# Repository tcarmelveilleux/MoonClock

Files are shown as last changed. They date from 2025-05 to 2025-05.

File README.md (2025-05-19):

# MoonClock

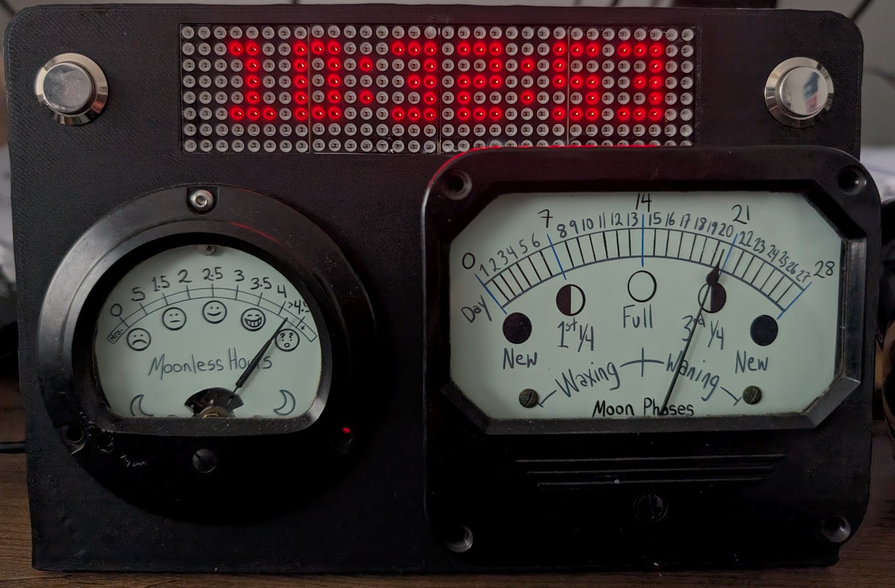
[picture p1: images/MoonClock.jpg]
MoonClock in action


A unique analog and digital clock that displays the current phase of the moon and the number of hours of darkness available for astronomical observation in the evening.

## Features

* **Analog Moon Phase Dial:** Visually represents the current lunar phase using a modified micro-ammeter.
* **Analog Darkness Hours Dial:** Indicates the duration of darkness in the evening after astronomical twilight, crucial for stargazing, using a modified micro-ammeter.
* **Digital Time Display:** A dot matrix display shows the current time.
* **Real-Time Clock (RTC):** Keeps accurate time, even when not powered.
* **3D Printed Frame:** The clock's frame is a single piece designed to be 3D printed.
* **Powered by Raspberry Pi RP2040:** Uses the WaveShare RP2040-Zero module for its easy to use form-factor.
* **CircuitPython Implementation:** The project is coded in CircuitPython, making it accessible and easy to modify.
* **Custom Astronomical Calculations:** Employs the `tcv_astro` module, specifically developed for this project using algorithms from astronomical literature (primarily "Astronomical Algorithms" by Jean Meeus).

## Hardware

* Raspberry Pi RP2040-based module (e.g., Waveshare RP2040-Zero)
* Real-Time Clock (RTC) module based on DS3231 (Rev 1) and MCP7940 (Rev 2)
* Dot matrix display based on MAX7219
* Modified micro-ammeters analog dials and associated DAC and amplifiers.
* 3D-printed frame (PETG)

## Software

* CircuitPython firmware for the Raspberry Pi RP2040
  * Custom build with Double Precision floating-point arithmetic enabled.
* `tcv_astro` CircuitPython module (containing astronomical calculation functions).
  * This module was written custom for this project to have very little dependencies.
* Libraries for controlling the RTC, dot matrix display, and the modified micro-ammeters (a lot of Adafruit CircuitPython libraries)

## `tcv_astro` Module

This project features a custom-built CircuitPython module, `tcv_astro`, which handles the necessary astronomical calculations. It implements algorithms described in Jean Meeus's "Astronomical Algorithms.":
  *  Meeus, J. (1991). Astronomical algorithms (1st ed.). Willmann-Bell.

This module computes:
* The current phase of the moon.
* Sunrise, sunset, moonset and moonrise times to determine the duration of evening darkness.

## Getting Started

Instructions for building and setting up your own MoonClock will be provided in future updates. This will include details on:

* 3D printing the frame.
* Modifying and wiring the micro-ammeters and other electronic components.
* Installing CircuitPython and necessary libraries.
* Uploading the code to the RP2040-Zero.

## Contributing

Contributions to this project are welcome! If you have ideas for improvements, bug fixes, or new features, please feel free to open an issue or submit a pull request.

## License

MIT license, see the LICENSE file.

## Acknowledgements

* The Raspberry Pi Foundation for the RP2040 microcontroller.
* The Afafruit CircuitPython community for their excellent libraries and support.
* Jean Meeus for his invaluable and authoritastive "Astronomical Algorithms" book

---

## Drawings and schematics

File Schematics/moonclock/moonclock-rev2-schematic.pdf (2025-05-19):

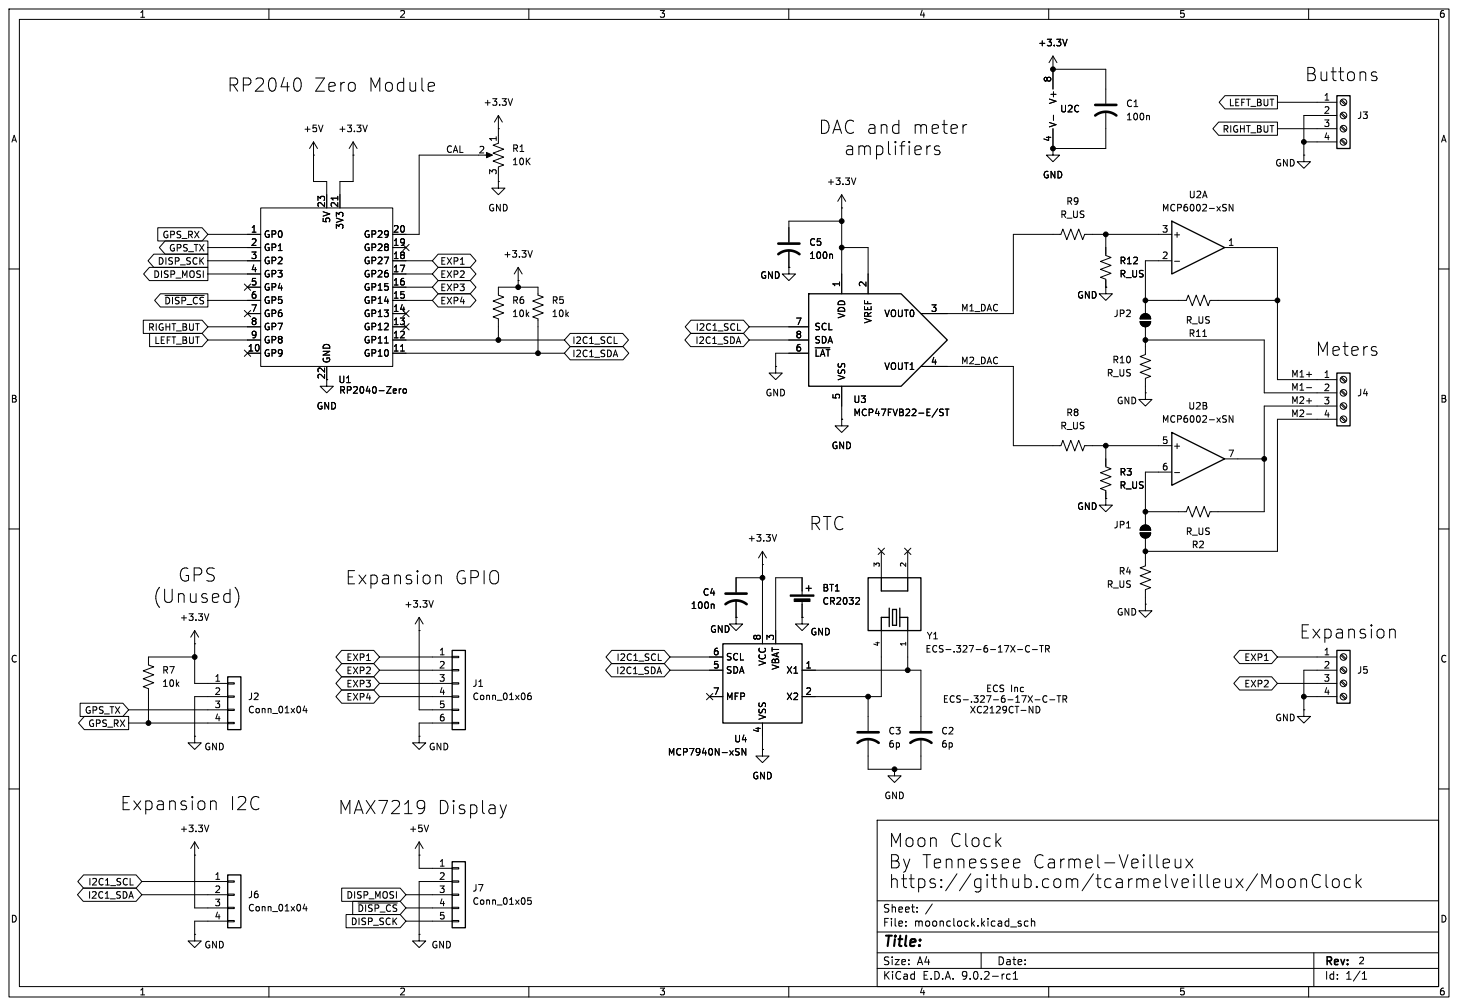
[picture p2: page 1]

By Tennessee Carmel-Veilleux
2 https://github.com/tcarmelveilleux/MoonClock

Id: 1/1 Title: File: moonclock.kicad_sch Sheet: /

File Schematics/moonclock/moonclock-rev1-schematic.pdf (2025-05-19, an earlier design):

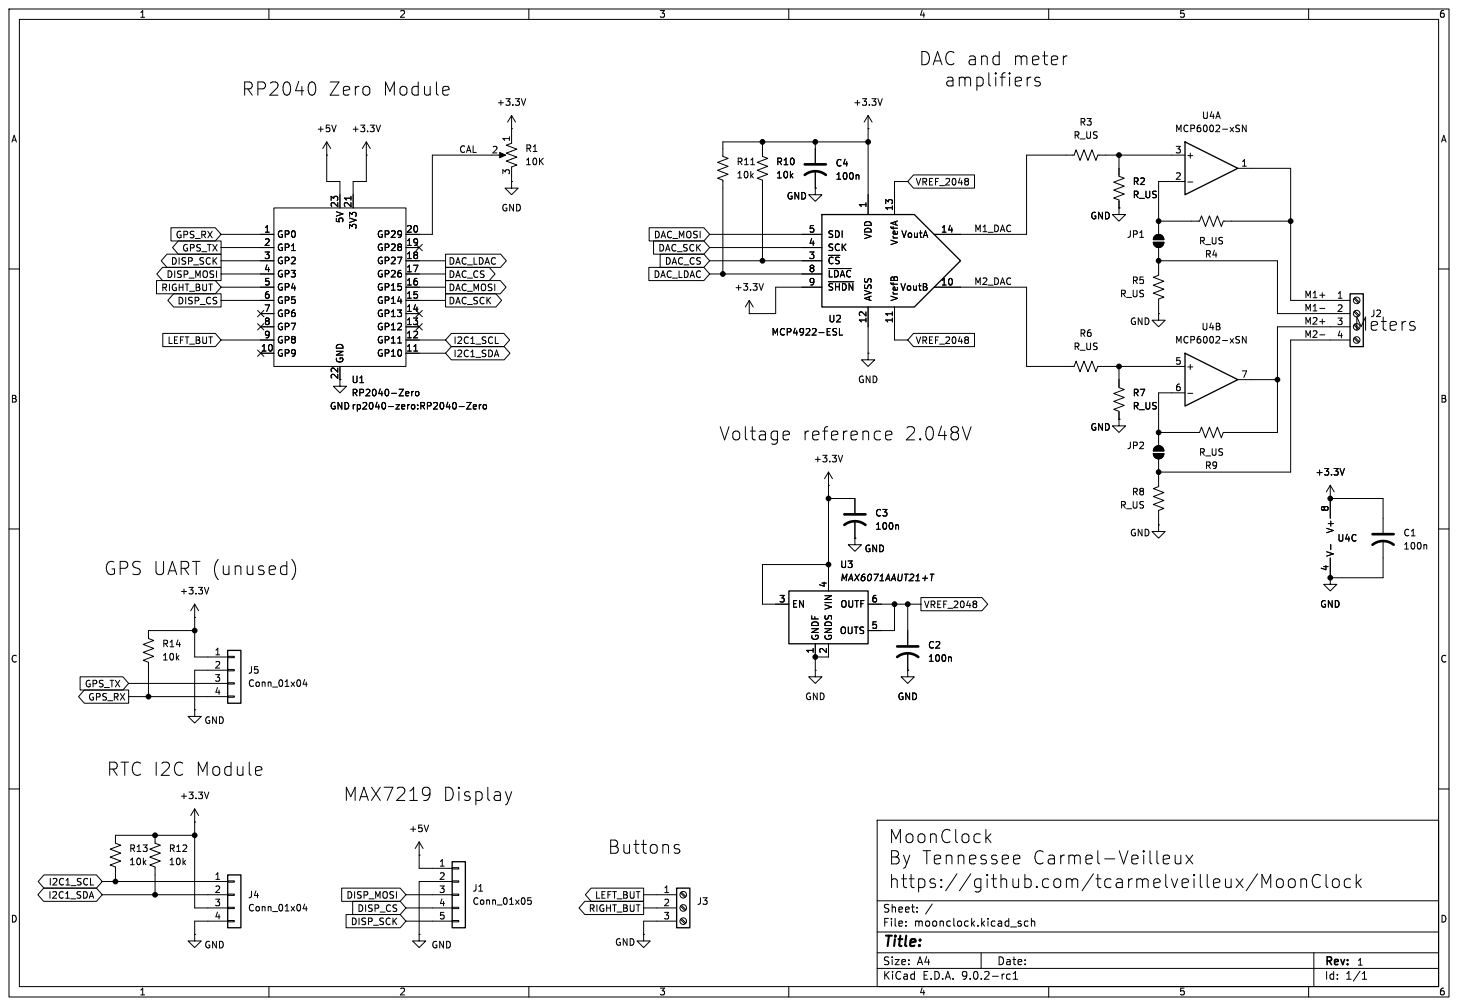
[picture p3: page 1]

1 AVSS 12 VrefA 13 VrefB 11 VoutA 14 VoutB 10 GND

1 AVSS 12 VrefA 13 VrefB 11 VoutA 14 VoutB 10 U2 MCP4922-ESL C2

2 OUTF 6 OUTS 5 U3 MAX6071AAUT21+T SDI 5 SCK 4 ~{CS} 3 ~{LDAC} 8 ~{SHDN} 9 VDD

MoonClock
By Tennessee Carmel-Veilleux
https://github.com/tcarmelveilleux/MoonClock

Id: 1/1 Title: File: moonclock.kicad_sch Sheet: /

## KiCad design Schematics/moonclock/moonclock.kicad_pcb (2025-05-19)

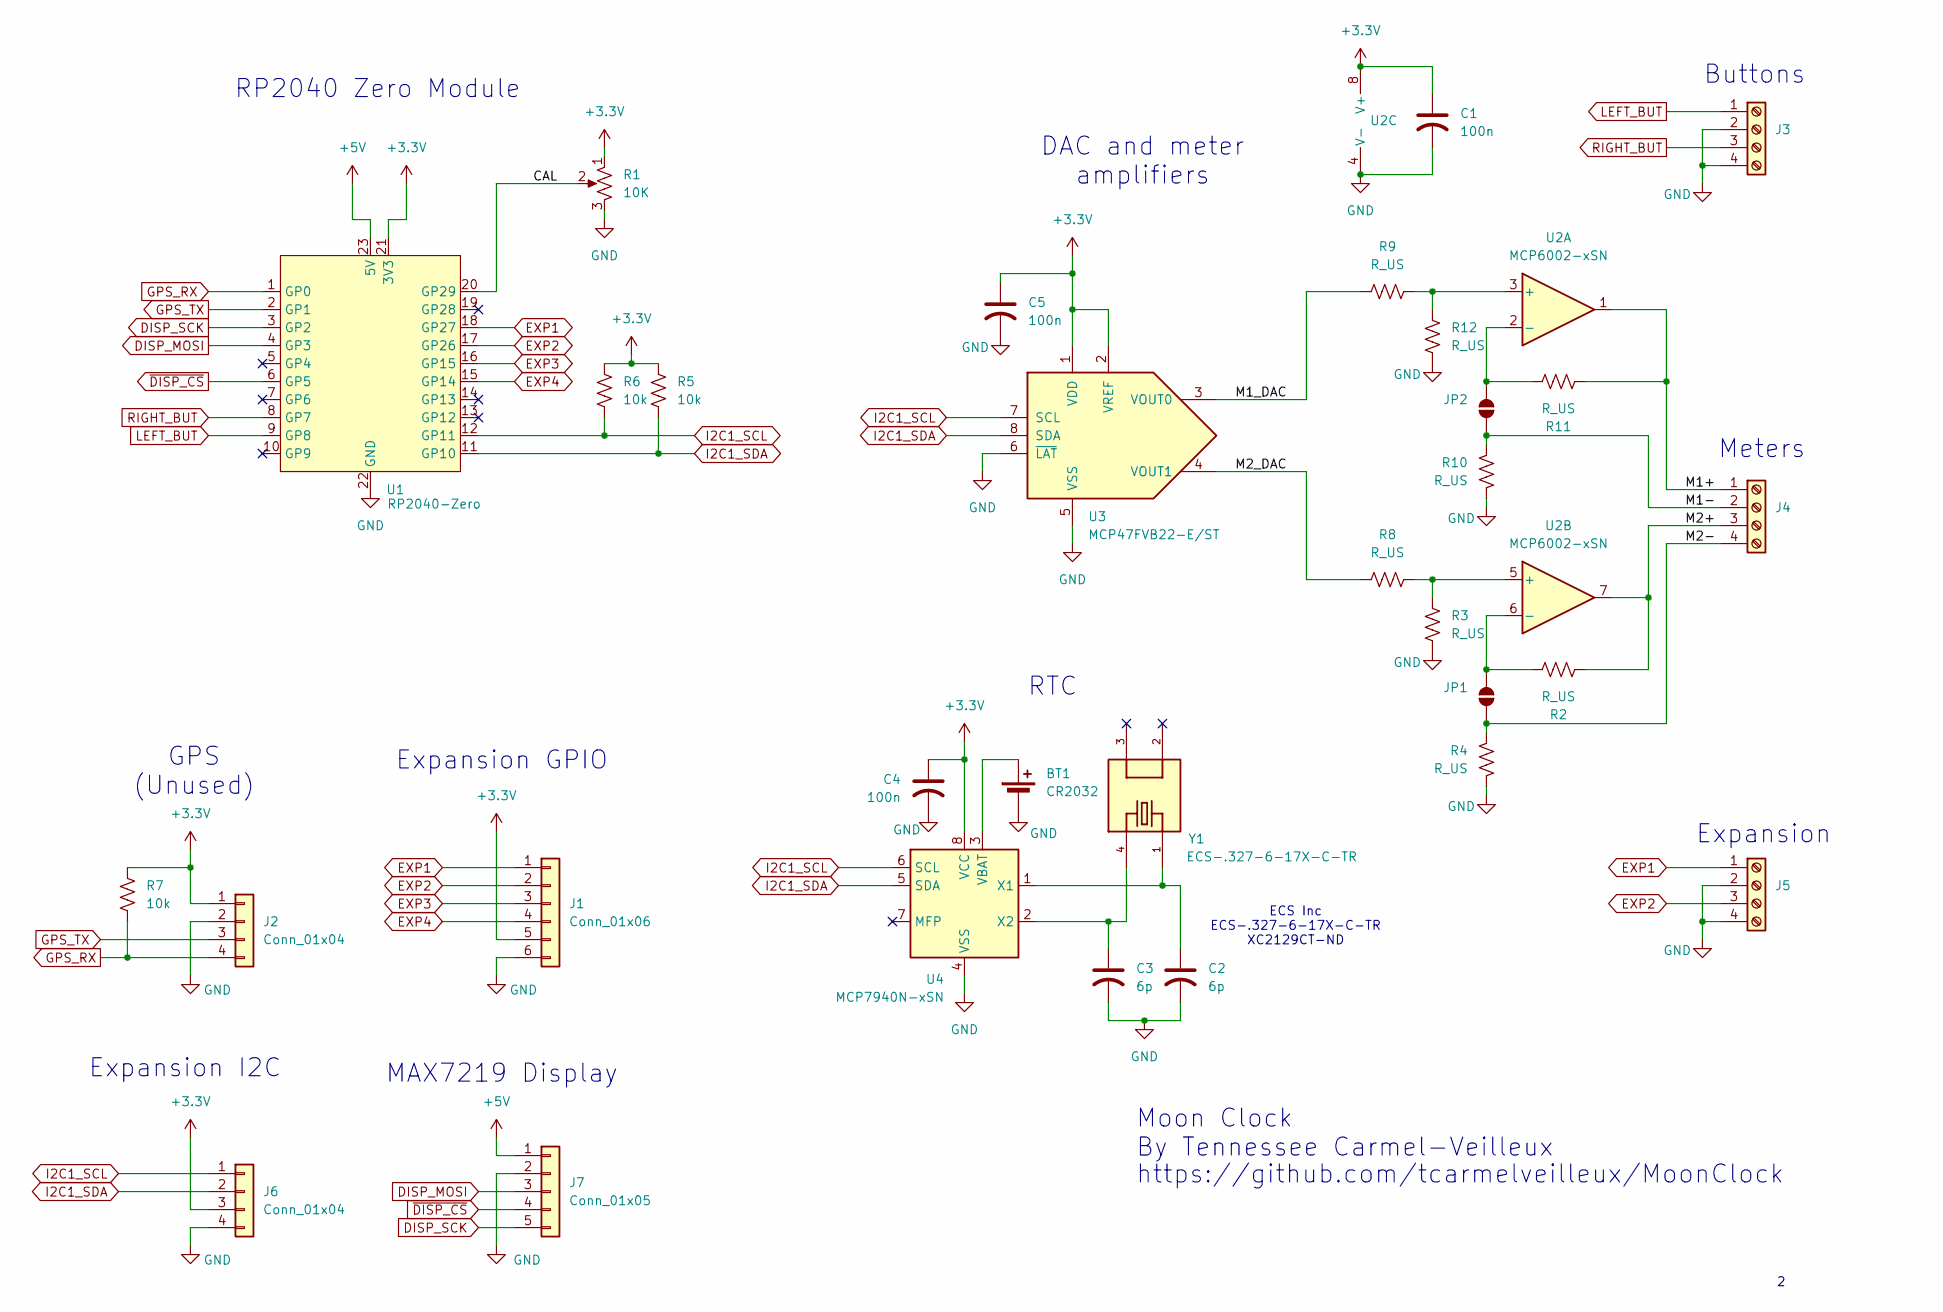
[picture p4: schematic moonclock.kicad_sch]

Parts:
BT1: CR2032; BAT_BS-7
C1, C4, C5: 100n; C_0805_2012Metric_Pad1.18x1.45mm_HandSolder
C2, C3: 6p; C_0603_1608Metric_Pad1.08x0.95mm_HandSolder
J1: Conn_01x06; PinHeader_1x06_P2.54mm_Vertical
J2, J6: Conn_01x04; PinHeader_1x04_P2.54mm_Vertical
J3, J4, J5: Screw_Terminal_01x04; TerminalBlock_Phoenix_MKDS-1,5-4-5.08_1x04_P5.08mm_Horizont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
J7: Conn_01x05; PinHeader_1x05_P2.54mm_Vertical
JP1, JP2: SolderJumper_2_Open; SolderJumper-2_P1.3mm_Open_RoundedPad1.0x1.5mm
R1: 10K; Potentiometer_Bourns_3296W_Vertical
R2, R3, R4, R8, R9, R10, R11, R12: R_US; R_0805_2012Metric_Pad1.20x1.40mm_HandSolder
R5, R6, R7: 10k; R_0805_2012Metric_Pad1.20x1.40mm_HandSolder
U1: RP2040-Zero
U2: MCP6002-xSN; SOIC-8_3.9x4.9mm_P1.27mm
U3: MCP47FVB22-E/ST; TSSOP-8_4.4x3mm_P0.65mm
U4: MCP7940N-xSN; SOIC-8_3.9x4.9mm_P1.27mm
Y1: ECS-.327-6-17X-C-TR; XTAL_ECS-.327-6-17X-C-TR; PARTREV 2016

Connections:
+3.3V: C1.1, C4.1, C5.1, J1.5, J2.1, J6.3, R1.1, R5.1, R6.1, R7.1, U1.21 (3V3), U2.8 (V+), U3.1 (VDD), U3.2 (VREF), U4.8 (VCC)
+5V: J7.1, U1.23 (5V)
/CAL: R1.2, U1.20 (GP29)
/M1+: J4.1, R11.2, U2.1
/M1-: J4.2, JP2.1 (A), R10.1
/M1_DAC: R9.1, U3.3 (VOUT0)
/M2+: J4.3, R2.2, U2.7
/M2-: J4.4, JP1.1 (A), R4.1
/M2_DAC: R8.1, U3.4 (VOUT1)
DISP_MOSI: J7.3, U1.4 (GP3)
DISP_SCK: J7.5, U1.3 (GP2)
EXP1: J1.1, J5.1, U1.18 (GP27)
EXP2: J1.2, J5.3, U1.17 (GP26)
EXP3: J1.3, U1.16 (GP15)
EXP4: J1.4, U1.15 (GP14)
GND: BT1.2 (-), C1.2, C2.2, C3.2, C4.2, C5.2, J1.6, J2.2, J3.2, J3.4, J5.2, J5.4, J6.4, J7.2, R1.3, R3.2, R4.2, R10.2, R12.2, U1.22 (GND), U2.4 (V-), U3.5 (VSS), U3.6 (~LAT), U4.4 (VSS)
GPS_RX: J2.4, R7.2, U1.1 (GP0)
GPS_TX: J2.3, U1.2 (GP1)
I2C1_SCL: J6.1, R6.2, U1.12 (GP11), U3.7 (SCL), U4.6 (SCL)
I2C1_SDA: J6.2, R5.2, U1.11 (GP10), U3.8 (SDA), U4.5 (SDA)
LEFT_BUT: J3.1, U1.9 (GP8)
unnamed: BT1.1 (+), U4.3 (VBAT)
unnamed: JP1.2 (B), R2.1, U2.6 (-)
unnamed: JP2.2 (B), R11.1, U2.2 (-)
unnamed: R9.2, R12.1, U2.3 (+)
unnamed: R3.1, R8.2, U2.5 (+)
unnamed: C2.1, U4.1 (X1), Y1.1
unnamed: C3.1, U4.2 (X2), Y1.4
RIGHT_BUT: J3.3, U1.8 (GP7)
~DISP_CS: J7.4, U1.6 (GP5)

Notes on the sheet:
DAC and meter amplifiers
https://github.com/tcarmelveilleux/MoonClock
Buttons
MAX7219 Display
ECS Inc ECS-.327-6-17X-C-TR XC2129CT-ND
Expansion GPIO
Moon Clock By Tennessee Carmel-Veilleux
RP2040 Zero Module
Expansion
RTC
GPS (Unused)
Meters
Expansion I2C

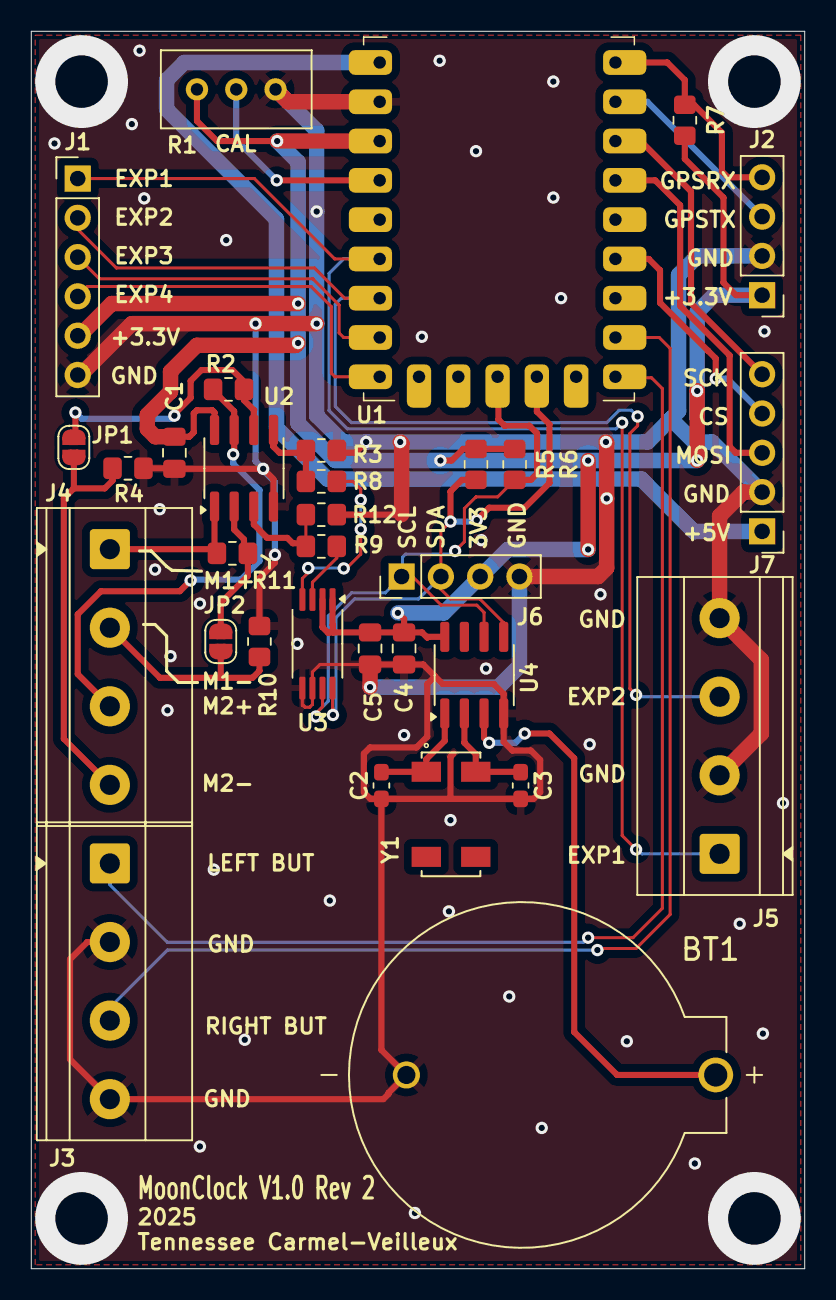
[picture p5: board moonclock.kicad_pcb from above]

Board: 2 copper layers, 50.0 x 80.0 mm, 32 parts (0 on the bottom side), 30 nets.

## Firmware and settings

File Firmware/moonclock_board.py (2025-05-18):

import board
import busio
import analogio
from digitalio import Pull, Direction, DigitalInOut
import microcontroller
import keypad
import neopixel
# import adafruit_gps
import select
import winterbloom_smolmidi as smolmidi
import usb_midi
from adafruit_bus_device.spi_device import SPIDevice
from adafruit_max7219.matrices import CustomMatrix
from adafruit_ds3231 import DS3231
from adafruit_bitmap_font import bitmap_font
import time

# Give us a chance to run GC on circuitpython
try:
    import gc
    def run_gc():
        gc.collect()
except:
    def run_gc():
        pass

try:
  import ujson as json
except ImportError:
  import json


FONT_FILE = "fonts/moonclock.bdf"

# Using CircuitPython 9.x with https://circuitpython.org/board/waveshare_rp2040_zero/
# CircuitPython tips: https://github.com/todbot/circuitpython-tricks
# SPI/I2C tutorial: https://www.digikey.ca/en/maker/projects/circuitpython-basics-i2c-and-spi/9799e0554de14af3850975dfb0174ae3

class MCP49xxDriver:
  def __init__(self, spi_device: SPIDevice, ldac_pin: DigitalInOut, resolution_bits: int):
    self._spi_device: SPIDevice = spi_device
    self._resolution_mask = (1 << resolution_bits) - 1
    self._ldac_pin = ldac_pin

  def load_dac_value(self, channel_idx: int, value: int):
    MCP49XX_CHAN_SEL_BIT = 1 << 15
    MCP49XX_BUF_EN_BIT = 1 << 14
    MCP49XX_UNITY_GAIN_BIT = 1 << 13
    MCP49XX_SHDN_BIT = 1 << 12

    if channel_idx > 1:
      raise ValueError("Bad channel")

    code_val = value & self._resolution_mask

    # Always active, always buffer enabled, always unity gain. Make your own driver if you don't like it.
    cfg_reg = MCP49XX_SHDN_BIT | MCP49XX_BUF_EN_BIT | MCP49XX_UNITY_GAIN_BIT

    cfg_reg |= MCP49XX_CHAN_SEL_BIT if (channel_idx != 0) else 0
    cfg_reg |= code_val

    with self._spi_device as spi:
      spi.write(bytes([cfg_reg >> 8, cfg_reg & 0xff]))

  def latch_dacs(self):
    self._ldac_pin.value = False
    self._ldac_pin.value = False

    self._ldac_pin.value = True


class MoonClock:
  def __init__(self):
    # DAC pins and SPI device
    self.dac_cs_pin = DigitalInOut(board.GP26)
    self.dac_cs_pin.pull = None
    self.dac_cs_pin.switch_to_output(value=True)

    self.dac_ldac_pin = DigitalInOut(board.GP27)
    self.dac_ldac_pin.pull = None
    self.dac_ldac_pin.switch_to_output(value=True)

    self.dac_spi = busio.SPI(board.GP14, MOSI=board.GP15)
    self.dac_spi_device = SPIDevice(self.dac_spi, chip_select=self.dac_cs_pin, baudrate=1000000, polarity=0, phase=0)

    self.dac_driver = MCP49xxDriver(self.dac_spi_device, ldac_pin=self.dac_ldac_pin, resolution_bits=12)
    self.dac_driver.load_dac_value(0, 0)
    self.dac_driver.load_dac_value(1, 0)
    self.dac_driver.latch_dacs()

    # Display pins and SPI device
    self.display_cs_pin = DigitalInOut(board.GP5)
    self.display_cs_pin.pull = None
    self.display_cs_pin.switch_to_output(value=True)

    self.font = bitmap_font.load_font(FONT_FILE)
    run_gc()
    self.display_spi = busio.SPI(board.GP2, MOSI=board.GP3)
    #self.display_spi_device = SPIDevice(self.display_spi, chip_select=self.display_cs_pin, baudrate=1000000, polarity=0, phase=0)
    self.display = CustomMatrix(spi=self.display_spi, cs=self.display_cs_pin, width=32, height=8)
    self.display.init_display()
    self.display.brightness(0)
    self.display.clear_all()
    self.display.show()
    run_gc()

    # ADC Input 1 (for debug, not used yet)
    self.pot_adc_in = analogio.AnalogIn(board.A3)

    # Button0 (left), Button1 (right)
    self.button_pins = (board.GP8, board.GP4)
    self.buttons = keypad.Keys(self.button_pins, value_when_pressed=False, pull=True)
    self.left_button_num = 0
    self.right_button_num = 1

    # I2C port (for debug, not used yet)
    self.SCL1_PIN = board.GP11
    self.SDA1_PIN = board.GP10
    self.i2c1 = busio.I2C(self.SCL1_PIN, self.SDA1_PIN, frequency=100_000)
    self.rtc = DS3231(self.i2c1)

    # # GPS UART0
    # self.GPS_TX0_PIN = board.GP0
    # self.GPS_RX0_PIN = board.GP1
    # self.gps_uart = busio.UART(self.GPS_TX0_PIN, self.GPS_RX0_PIN, baudrate=9_600)

    # self.gps = adafruit_gps.GPS(self.gps_uart, debug=False)

    # NeoPixel
    self.neopixel = neopixel.NeoPixel(board.NEOPIXEL, 1, brightness=0.1)
    self.neopixel.fill(0xFFFF00)

    self.midi_in = smolmidi.MidiIn(usb_midi.ports[0])

    self._poll = select.poll()
    self._poll.register(usb_midi.ports[0], select.POLLIN)


  def process_midi(self, handler: callable) -> bool:
    for _ in self._poll.ipoll(0):
      msg_in = self.midi_in.receive()
      if msg_in is None: continue

      if msg_in.type == smolmidi.SYSEX:
        sysex_payload, truncated = self.midi_in.receive_sysex(128)
        handler("".join([chr(b) for b in sysex_payload]))


  def load_json_settings(self) -> dict:
    json_str = []
    try:
      for byte_idx in range(len(microcontroller.nvm)):
        b = microcontroller.nvm[byte_idx]
        if b == 0 or b == 0xff:
          json_data = "".join(json_str)
          print("Loaded settings: ", json_data)
          return json.loads(json_data)
        else:
          json_str.append(chr(b))
    except Exception as e:
      print("Error loading settings: %s" % e)
      return {}


  def save_json_settings(self, val: dict):
    try:
      serialized_bytes = json.dumps(val).encode('utf-8')
      print("Saving: ", serialized_bytes)
      all_bytes = serialized_bytes + '\x00'
      microcontroller.nvm[0:len(all_bytes)] = all_bytes
    except Exception as e:
      print("ERROR SAVING SETTINGS: %s!" % e)


  def display_text(self, sx: int, sy: int, msg: str) -> None:
    font = self.font
    _, height, _, dy = font.get_bounding_box()
    font.load_glyphs(msg)

    if isinstance(self, MoonClock):
      disp = self.display
    else:
      disp = self

    for y in range(height):
        x = sx
        for c in msg:
            npix = 0

            glyph = font.get_glyph(ord(c))
            if not glyph:
                continue
            glyph_y = y + (glyph.height - (height + dy)) + glyph.dy
            if 0 <= glyph_y < glyph.height:
                for i in range(glyph.width):
                    value = glyph.bitmap[i, glyph_y]
                    disp.pixel(x, sy + y, value)
                    x += 1
                    npix += 1
            else:
                # empty section for this glyph
                for i in range(glyph.width):
                    disp.pixel(x, sy + y, 0)
                    x += 1
                    npix += 1
            for _ in range(glyph.shift_x - npix):
                disp.pixel(x, sy + y, 0)
                x += 1

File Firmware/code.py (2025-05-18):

from moonclock_board import MoonClock
from tcv_astro.angles import hours_to_hms
from tcv_astro import moon
from tcv_astro.polynomial import linear_interp_in_parts
from tcv_astro import julian, polynomial
from tcv_astro.event_times import get_event_time, get_sun_positions_for_event, get_moon_positions_for_event, RiseTransitSetTimes
from adafruit_datetime import datetime, timedelta
from adafruit_max7219.matrices import CustomMatrix

import time
# Give us a chance to run GC on circuitpython
try:
    import gc
    def run_gc():
        gc.collect()
except:
    def run_gc():
        pass

try:
    import machine
    def reboot():
        machine.reset()
except:
    def reboot():
        pass

CHANNEL_MOON_PHASE = 0
CHANNEL_MOONLESS_HOURS = 1

NUM_SECONDS_TO_RESET_DISPLAY = 127

def debug_print(*args):
  print(*args)

def pt(l, t):
  debug_print("{} {:02}/{:02} {:02}:{:02}".format(l, t.month, t.day, t.hour, t.minute))


MOONLESS_HOURS_POINTS = [
  (0, 410),
  (0.25, 610),
  (0.5, 800),
  (1.0, 1000),
  (1.5, 1180),
  (1.75, 1380),
  (2.0, 1570),
  (2.25, 1775),
  (2.5, 1965),
  (2.75, 2160),
  (3.0, 2355),
  (3.25, 2560),
  (3.5, 2750),
  (3.75, 2950),
  (4.0, 3150),
  (4.25, 3355),
  (4.5, 3555),
]


class RiseSetEvent:
  def __init__(self, moment: datetime, is_rise: bool):
    self.moment: datetime = moment
    self.is_rise: bool = is_rise

class RiseSetTimes:
  def __init__(self, rise_time: datetime, set_time: datetime):
    self.rise_time = rise_time
    self.set_time = set_time


def get_date_of_nth_weekday_of_month(year: int, month: int, weekday: int, num: int) -> int:
  date_iter = datetime(year, month, 1, 0, 0, 0)
  cur_num = 0

  while date_iter.month == month:
    if date_iter.weekday() == weekday:
      cur_num += 1

    if cur_num == num:
      return date_iter.day

    date_iter += timedelta(days=1)

  raise ValueError("Never found the correct day")


class MoonClockSettings:
  def __init__(self, moon_clock: MoonClock):
    self.moon_clock = moon_clock
    self.settings_dict = {
        "utc_offset_seconds": 0,
        "latitude_millionths": 43451600,
        "longitude_millionths": 80492500,
        "dst_strategy": "canada"
    }
    self.is_test_mode = False

  def process_sysex_setting(self, setting: str):
    debug_print("Got SysEx setting command: ", setting)
    tokens = setting.split(',')
    need_save: bool = False

    try:
      if tokens[0] == "UTC":
        hours = int(tokens[1])
        minutes = int(tokens[2])
        seconds = int(tokens[3])

        current_time = self.moon_clock.rtc.datetime
        new_time = time.struct_time((current_time.tm_year, current_time.tm_mon, current_time.tm_mday, hours, minutes, seconds, current_time.tm_wday, -1, -1))
        self.moon_clock.rtc.datetime = new_time
      elif tokens[0] == "DATE":
        year = int(tokens[1])
        month = int(tokens[2])
        day = int(tokens[3])
        dow = int(tokens[4])

        current_time = self.moon_clock.rtc.datetime
        new_time = time.struct_time((year, month, day, current_time.tm_hour, current_time.tm_min, current_time.tm_sec, dow, -1, -1))
        self.moon_clock.rtc.datetime = new_time
      elif tokens[0] == "OFFSET":
        self.settings_dict["utc_offset_seconds"] = int(tokens[1])
        need_save = True
      elif tokens[0] == "DST":
        self.settings_dict["dst_strategy"] = tokens[1]
        need_save = True
      elif tokens[0] == "POS":
        self.settings_dict["latitude_millionths"] = int(tokens[1])
        self.settings_dict["longitude_millionths"] = int(tokens[2])
        need_save = True
      elif tokens[0] == "STOPCAL":
        self.is_test_mode = False
      elif tokens[0] == "CAL":
        self.is_test_mode = True
        channel = int(tokens[1]) % 2
        value = int(tokens[2]) % 4096
        # Enter interactive calibration mode with value 4095, otherwise just push value to DAC from sysex.
        if value < 4095:
          self.moon_clock.dac_driver.load_dac_value(channel, value)
          self.moon_clock.dac_driver.latch_dacs()
        else:
          self.run_interactive_cal(channel)

    except Exception as e:
      debug_print('Error processing sysex "%s": %s' % (setting, e))
      return

    if need_save:
      self.save_settings()

  def run_interactive_cal(self, channel: int):
    """Run a loop of grabbing ADC and sending it to DAC, with printing, until set to max value."""
    while True:
      adc_value = 0
      for _ in range(16):
          adc_value += self.moon_clock.pot_adc_in.value
      adc_value = adc_value // 16

      # ADC_value always 0..65535
      if adc_value > 65300:
        self.is_test_mode = False
        return

      dac_value = adc_value >> 4
      self.moon_clock.dac_driver.load_dac_value(channel, dac_value)
      self.moon_clock.dac_driver.latch_dacs()
      print("Channel %d DAC Value: %d" % (channel, dac_value))

  def load_settings(self):
    settings_dict = self.moon_clock.load_json_settings()
    if not settings_dict:
      debug_print(settings_dict)
      self.save_settings()
      return

    self.settings_dict.update(settings_dict)

  def save_settings(self):
    self.moon_clock.save_json_settings(self.settings_dict)


  def get_dst_hours_delta(self, local_datetime_before_dst: datetime) -> timedelta:
    strategy = self.settings_dict["dst_strategy"]
    if strategy == "none":
      return timedelta(0)

    if strategy == "canada":
      # On the second Sunday in March, at 2:00 a.m. EST, clocks are advanced to 3:00 a.m. EDT,
      # creating a 23-hour day. On the first Sunday in November, at 2:00 a.m. EDT,
      # clocks are moved back to 1:00 a.m. EST, which results in a 25-hour day
      SUNDAY = 6
      MARCH = 3
      NOVEMBER = 11

      month = local_datetime_before_dst.month
      day = local_datetime_before_dst.day
      hour = local_datetime_before_dst.hour

      second_sunday_of_march = get_date_of_nth_weekday_of_month(local_datetime_before_dst.year, MARCH, SUNDAY, num=2)
      first_sunday_of_october = get_date_of_nth_weekday_of_month(local_datetime_before_dst.year, NOVEMBER, SUNDAY, num=1)
      if month >= MARCH and month <= NOVEMBER:
        if month == MARCH:
          if day >= second_sunday_of_march and hour >= 2:
            return timedelta(hours=1)
          else:
            return timedelta(hours=0)
        elif month == NOVEMBER:
          if day <= first_sunday_of_october and hour < 1:
            return timedelta(hours=1)
          else:
            return timedelta(hours=0)
        else:
          return timedelta(hours=1)

    return timedelta(hours=0)

  def to_local_time(self, now_utc_datetime: datetime) -> datetime:
    local_datetime_before_dst = now_utc_datetime + timedelta(seconds=self.settings_dict["utc_offset_seconds"])
    dst_offset = self.get_dst_hours_delta(local_datetime_before_dst)
    local_datetime = local_datetime_before_dst + dst_offset

    return local_datetime
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

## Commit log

2025-04-13 Added screen management framework
2025-04-26 Added schematic and PCB
    [moonclock-B_Cu.gbl, moonclock-B_Mask.gbs, moonclock-B_Silkscreen.gbo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]
2025-05-04 Try to fix daily crash
    [code.py]
2025-05-04 Minor PCB updates
    [moonclock.kicad_pcb]
2025-05-11 Start on rev 2 design
    [moonclock.kicad_pcb, moonclock.kicad_sch]
2025-05-11 Fix 3.3V label
    [moonclock.kicad_pcb]
2025-05-18 Rev 1 PCB working, fixed refdes C4/R8, fixed moon phase cal
2025-05-18 Finished Rev2 pre-gerber
    [moonclock.kicad_pcb, moonclock.kicad_sch]
2025-05-18 Remove garbage RP2040 zero footprint from GH after redo
2025-05-18 Moved gerbers from Rev1
    [moonclock-B_Cu.gbl, moonclock-B_Mask.gbs, moonclock-B_Silkscreen.gbo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]
2025-05-18 Fix footprint for U1 and corner vias
    [moonclock.kicad_pcb, moonclock.kicad_sch]
2025-05-19 Rev2 hardware ready
    [moonclock.kicad_pcb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]
2025-05-19 Add title block to schematic and update rp2040 library location
    [moonclock.kicad_sch]
2025-05-19 Fix rp2040 library association
    [moonclock.kicad_sch]
2025-05-19 Schematic cosmetic improvements and PDF plot
    [moonclock.kicad_pcb, moonclock.kicad_sch]
2025-05-19 Schematic cosmetic improvements
2025-05-19 Add rev 1 schematic to master
